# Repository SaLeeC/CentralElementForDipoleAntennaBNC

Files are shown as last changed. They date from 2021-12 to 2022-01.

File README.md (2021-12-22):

# Central Element For Dipole Antenna BNC

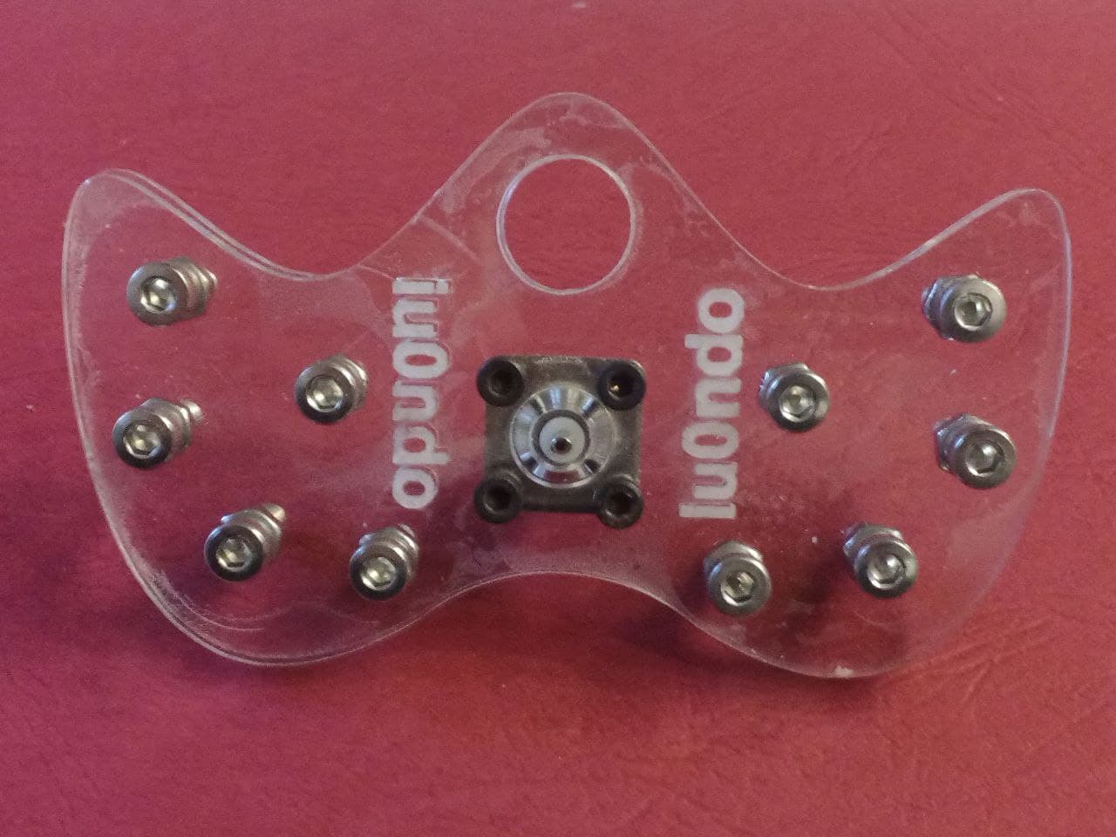
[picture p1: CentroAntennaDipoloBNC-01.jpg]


# Central Element For Dipole Antenna with a BNC connector

This dipole core is designed for use with a BNC connector with 4 screw holes. The element is composed of two pieces laser cut from a 3mm Plexiglass sheet. The two pieces have been glued together to increase their mechanical strength.

The connector is connected to two rings consisting of 5 screws each. The central screw is for connecting the connector (hot pole and GND) and the 4 peripheral screws are used to connect up to 4 different dipoles.

The project was created with FreeCad (19.x) and the folder contains the .DXF files ready for laser cutting

# Elemento centrale per antenna a dipolo con connettore BNC

Questo nucleo dipolo è progettato per l'uso con un connettore BNC con 4 fori per le viti. L'elemento è composto da due pezzi tagliati al laser da una lastra di plexiglass da 3 mm. I due pezzi sono stati incollati tra loro per aumentarne la resistenza meccanica.

Il connettore è collegato a due anelli composti da 5 viti ciascuno. La vite centrale serve per il collegamento del connettore (polo caldo e GND) e le 4 viti periferiche servono per collegare fino a 4 dipoli differenti. 

Il progetto è stato creato con FreeCad (19.x) e la cartella contiene i file .DXF pronti per il taglio laser

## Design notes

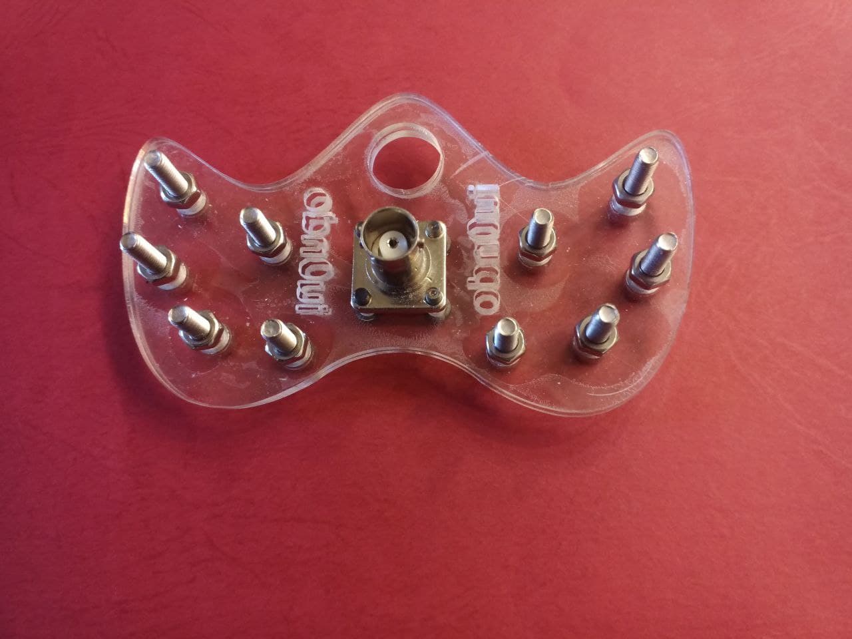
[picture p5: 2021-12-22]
CentroAntennaDipoloBNC-00.jpg

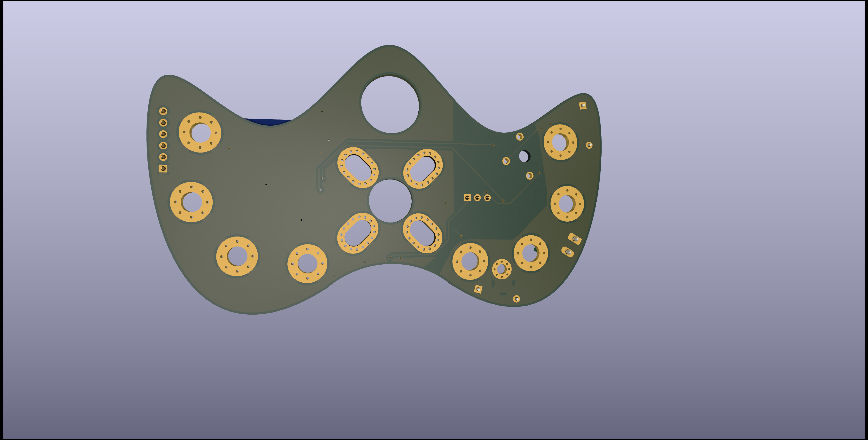
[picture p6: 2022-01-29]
KiCad/AntenneCentraleDipoloStrumentato-Retro.png

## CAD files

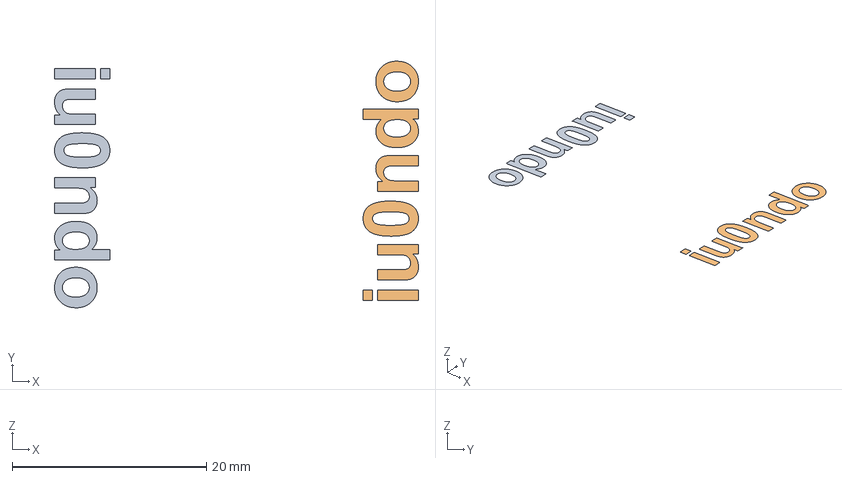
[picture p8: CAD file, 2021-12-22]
CentraleDipolo-BNC-4Viti.FCStd
37.5 x 25.4 x 0 mm
ShapeString
ShapeString001

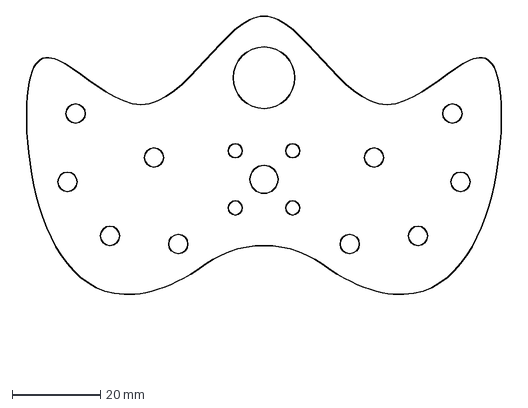
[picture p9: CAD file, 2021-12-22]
CentraleDipolo-BNC-4Viti-Posteriore.dxf
112.5 x 79.9 mm

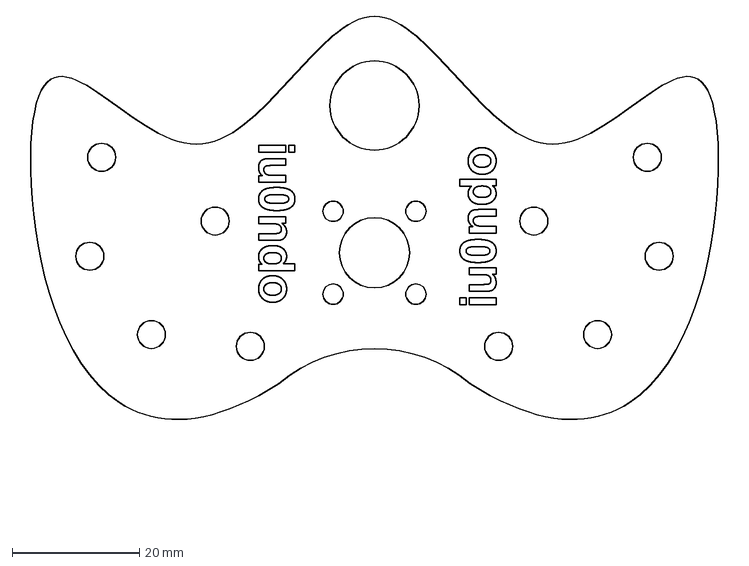
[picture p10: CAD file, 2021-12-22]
CentraleDipolo-BNC-4Viti-Centrale.dxf
112.5 x 79.9 mm

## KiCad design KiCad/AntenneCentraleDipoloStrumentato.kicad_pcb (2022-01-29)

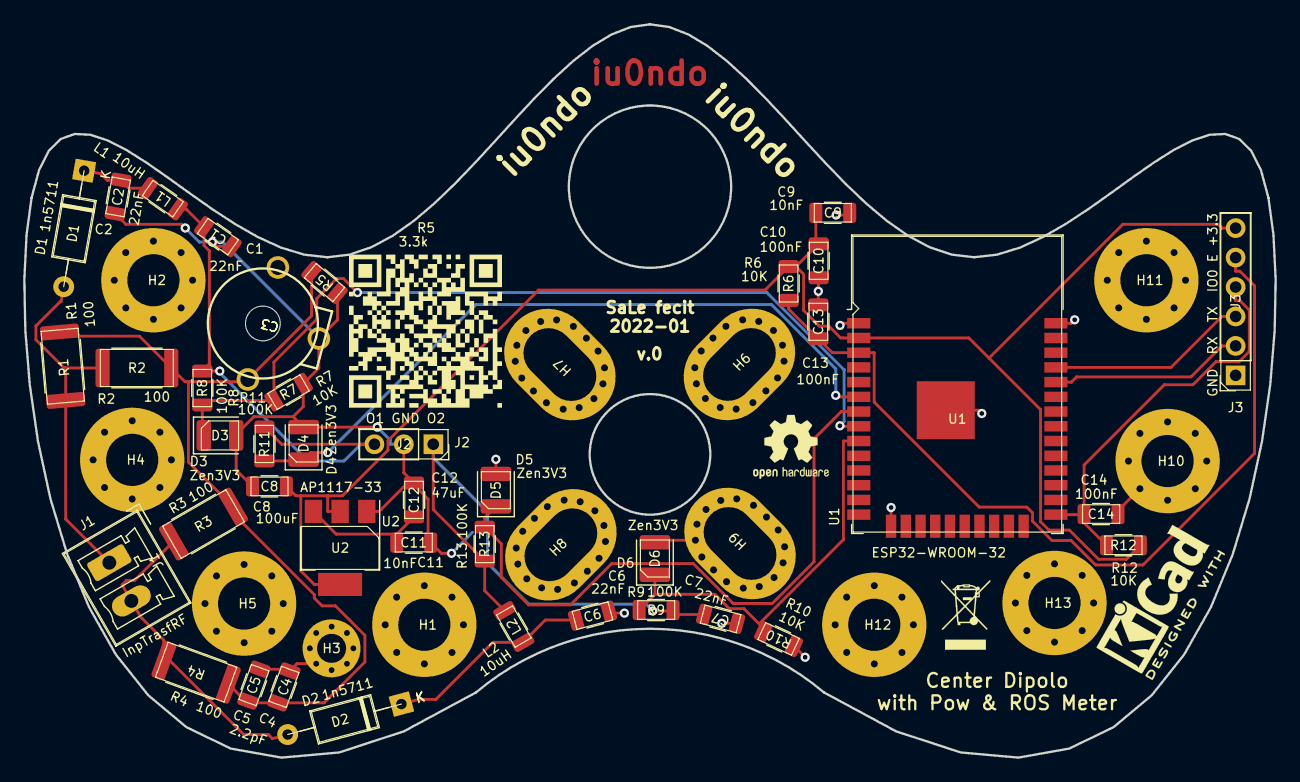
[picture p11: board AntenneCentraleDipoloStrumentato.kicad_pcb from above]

Board: 2 copper layers, 107.9 x 63.2 mm, 54 parts (0 on the bottom side), 19 nets.

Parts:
C1, C2, C6, C7: 22nF; R_1206_3216Metric
C3: C_Trim; GZC10100
C4, C5: 2.2pF; R_1206_3216Metric
C8: 100uF; R_1206_3216Metric
C9, C11: 10nF; R_1206_3216Metric
C10, C13, C14: 100nF; R_1206_3216Metric
C12: 47uF; R_1206_3216Metric
D1, D2: 1n5711; D_A-405_P10.16mm_Horizontal
D3, D4, D5, D6: Zen3V3; D_1210_3225Metric
H1, H2, H4, H5, H10, H11, H12, H13: MountingHole_4.5mm_Pad_Via
H3: MountingHole_2.5mm_Pad_Via
H6, H7, H8, H9: MountingHole_4.3x7mm_M4_Pad_Via
J1: InpTrasfRF; PhoenixContact_MCV_1,5_2-G-3.81_1x02_P3.81mm_Vertical
J2: O1 GND O2; PinSocket_1x03_P2.54mm_Vertical
J3: GND RX TX IO0 E +3.3; PinSocket_1x06_P2.54mm_Vertical
L1, L2: 10uH; L_1206_3216Metric
QR0001: github.com/SaLeeC/CentralElementForDipoleAntennaB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; //github.com/SaLeeC/CentralElementForDipoleAntennaBNC
R1, R2, R3, R4: 100; R_2512_6332Metric
R5: 3.3k; R_1206_3216Metric
R6, R7, R10, R12: 10K; R_1206_3216Metric
R8, R9, R11, R13: 100K; R_1206_3216Metric
U1: ESP32-WROOM-32
U2: AP1117-33; SOT-223-3_TabPin2

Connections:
GND: C1.1, C2.1, C3.2, C6.1, C7.1, C8.1, C9.1, C10.1, C11.1, C12.1, C13.1, C14.1, D3.2 (A), D4.2 (A), D5.2 (A), D6.2 (A), H6.1, H7.1, H8.1, H9.1, H10.1, H11.1, H12.1, H13.1, J2.2, J3.1, R5.1, R7.1, R10.1, U1.1 (GND), U1.15 (GND), U1.38 (GND), U1.39 (GND), U2.1 (GND)
unnamed: C1.2, J2.3, L1.1, R8.1, R11.2
unnamed: C2.2, D1.1 (K), L1.2
unnamed: C3.1, C4.1, C5.1, R1.2, R2.2, R3.1, R4.1, R5.2
unnamed: C4.2, C5.2, H1.1, H2.1, H3.1, H4.1, H5.1
unnamed: C6.2, D2.1 (K), L2.1
unnamed: C7.2, J2.1, L2.2, R9.2, R13.1
unnamed: C8.2, C9.2, C10.2, J3.6, R6.2, R12.2, U1.2 (VDD), U2.2 (VO)
unnamed: C11.2, C12.2, U2.3 (VI)
unnamed: C13.2, J3.5, R6.1, U1.3 (EN)
unnamed: C14.2, J3.4, R12.1, U1.25 (IO0)
unnamed: D1.2 (A), J1.1, R1.1, R2.1
unnamed: D2.2 (A), J1.2, R3.2, R4.2
unnamed: D3.1 (K), R7.2, R8.2, U1.8 (IO32)
unnamed: D4.1 (K), R11.1, U1.6 (IO34)
unnamed: D5.1 (K), R13.2, U1.7 (IO35)
unnamed: D6.1 (K), R9.1, R10.2, U1.9 (IO33)
unnamed: J3.2, U1.34 (RXD0/IO3)
unnamed: J3.3, U1.35 (TXD0/IO1)
